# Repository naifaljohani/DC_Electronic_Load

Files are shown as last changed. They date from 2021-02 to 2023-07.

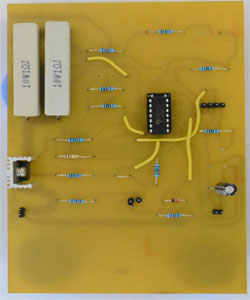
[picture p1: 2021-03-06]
Hardware/Mosfet circuit.JPG

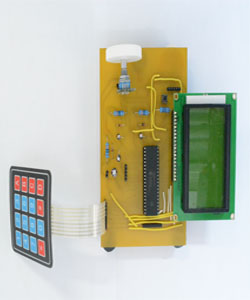
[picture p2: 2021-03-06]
Hardware/controlboard.jpg

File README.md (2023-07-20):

This is a proof of concept for a basic implementation using PIC16F1779 MCU from Microchip Technologies which has a plenty of analog features that could be very helpful to design an Electronic DC load that is affordable with acceptable features and performance.

-------------------- Project pictures----- v0--- now archive--

Mosfet circuit

controlboard

-------------------- Project pictures----- v1







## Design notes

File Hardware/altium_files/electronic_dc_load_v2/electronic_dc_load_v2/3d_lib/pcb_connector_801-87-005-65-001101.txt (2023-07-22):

"Symbol";"Value";"Unit";
"TraceParts.PartNumber";"10-20122013-093719";"";
"REFERENCE";"801-87-005-65-001101";"";
"TraceParts.PartTitle";"Press-fit socket connector 2.54 mm, single row, compliant pin for PCB thickness 1.5 to 2.5 mm - Mating pin Ø 0.76 mm";"";
"TraceParts.InstanceId";"10-20122013-0937193XV6ZG86OUMGCBDYINW9DIJ34";"";
"DESIGN";"Press-fit socket connector 2.54 mm, single row, compliant pin for PCB thickness 1.5 to 2.5 mm, 5 contacts, Tin / Flash Gold";"";
"TraceParts.PartStatus";"Published";"";
"TraceParts.PartStatusId";"";"";
"SUPPLIER";"preci-dip";"";
"TraceParts.PartVersion";"1.0.9";"";
"TRACEPARTS";"TRACEPARTS";"";
"TraceParts.PartLanguage";"en";"";
"TraceParts.ClassPath";"PRECIDIP:10-20122013-093719";"";

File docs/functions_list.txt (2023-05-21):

MCU firmware function list:
1.	Serial command scan:
a.	USART interrupt on command receive.   
2.	Serial data podcasting.
a.	USART interrupt on command transmit.
3.	Safety events reactions:
a.	Over heat event set load shut off.
b.	Voltage overload set load shut off.
c.	Current overload set load shut off.
4.	ADC functions :
a.	Initialization. 
b.	Read.
5.	DAC functions:
a.	Initialization. 
b.	Write.
6.	Mode control:
a.	Mode parameters set.
b.	Constant current PID control.
c.	Constant voltage PID control.
d.	Constant resistance PID control.
e.	Constant power PID control.
f.	Load on off.
7.	External Triggering:
a.	Triggering parameters set.
b.	External interrupt to load control.
8.	Output functions:
a.	 Square wave parameters set.

GUI functions and threads:
1.	Thread to display:
a.	Labels for current, voltage, resistance, power, mode selection.
b.	Buttons to set parameters:
i.	CC
ii.	CV
iii.	CR
iv.	CW
v.	EX TRIG
vi.	F(x)
vii.	SET
viii.	ON/OFF
ix.	Data logging.
c.	Menu to choose:
i.	Output function.
2.	Thread for ON/OFF command.
3.	Thread for parameters transmission.
4.	Thread for data logging.

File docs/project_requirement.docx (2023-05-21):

The final project is to be a USB controlled Electronic DC load, with the following features:

1. Current range of "5A -15mA".( to be verified)
2. Voltage range of "50V-1mV".( to be verified)
3. Connecting to a USB port as a serial device.
4. Controlled via an application GUI throw the serial port.
5. Powered via USB. (to be verified)
6. Has the four basic modes: CC, CV, CR, and CW.
7. Data logging in any mode.
8. External triggering.
9. Output functions, initially square wave.

Communications of data internally between functions and externally:

1. Static :
  a. Average rate
  b. Maximum rate
  c. Peak rate
2. Dynamic(FIFO):
  a. Average rate
  b. Maximum rate
  c. Peak rate

Timing:

1. Total execution time of the main function.
2. Rate of execution with a tolerance of ….+-. (to be added to the function list)
3. Response time with a tolerance of ….+- . (to be added to the function list)

Preliminary list of system modes with short description:

1. Powered down:
2. Idle:
3. Constant current:
4. Constant voltage:
5. Constant resistance:
6. Constant power:
7. External triggering:
8. Output functions:
9. Error :

Priority list: (for function execution)

1. Powered down:
2. Idle mode:
  a. High priority:
    i. …….
    ii. ………
  b. Medium priority:
    i. …….
  c. Low priority:
    i. …….
3. Constant current:
4. Constant voltage:
5. Constant resistance:
6. Constant power:
7. External triggering:
8. Output functions:
9. Error :

Mode execution based on the following triggering events table:

Original Mode | Next Mode | Triggering Event
Powered down | Error | Initial power up

Housekeeping functions (has no particular priority and execution time)

Error handling : ( a list with how it will be detected and how the system should respond to it)

1. Soft errors.
  a. Fault ……
    i. Test:
    ii. Response:
2. Recoverable errors.
  a. Fault ……
    i. Test:
    ii. Response:
3. Unrecoverable errors.
  a. Fault ……
    i. Test:
    ii. Response:
4. Hard errors:
  a. Watch dog timer
  b. Brownout reset
  c. Program data corruption
  d. Fault ……
    i. Test:
    ii. Response:

Task list: (list of tasks contains a set of functions, combining tasks is desirable if compatible, if not, a separation of incompatible tasks in timing or peripherals or has any conflict in any aspect, is easier to manage and less overhead)

1. Task1:
  a. Function1.
  b. Function2.
  c. …….

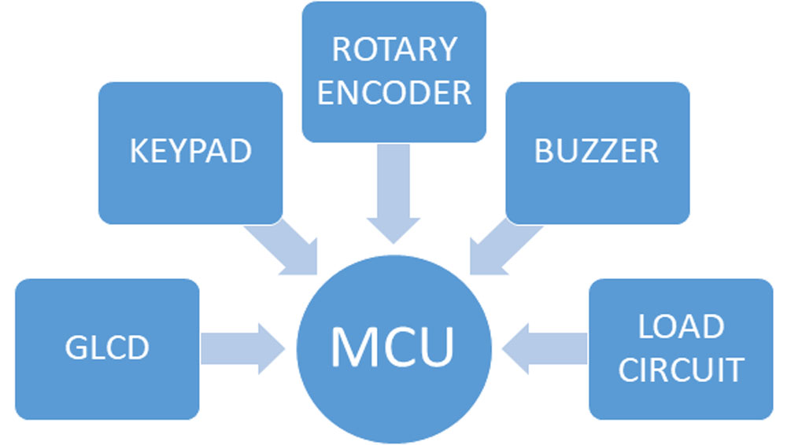
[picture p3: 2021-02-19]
Hardware/BLOCK_DIAGRAM.jpg

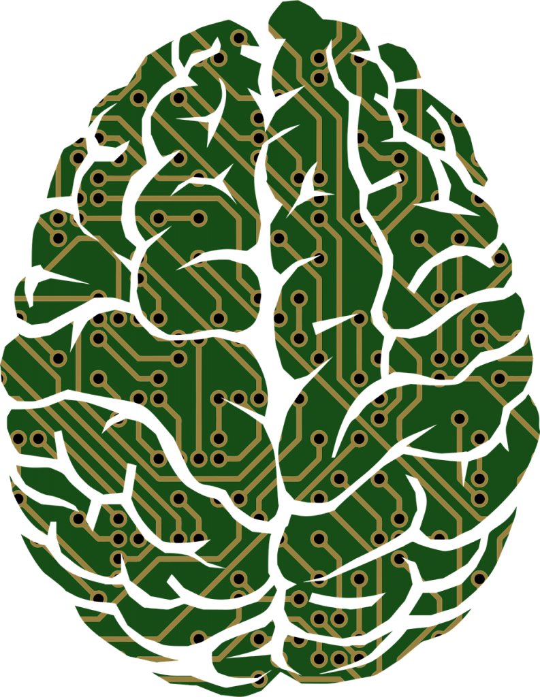
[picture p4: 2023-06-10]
Firmware/latex/nmn,.jpg

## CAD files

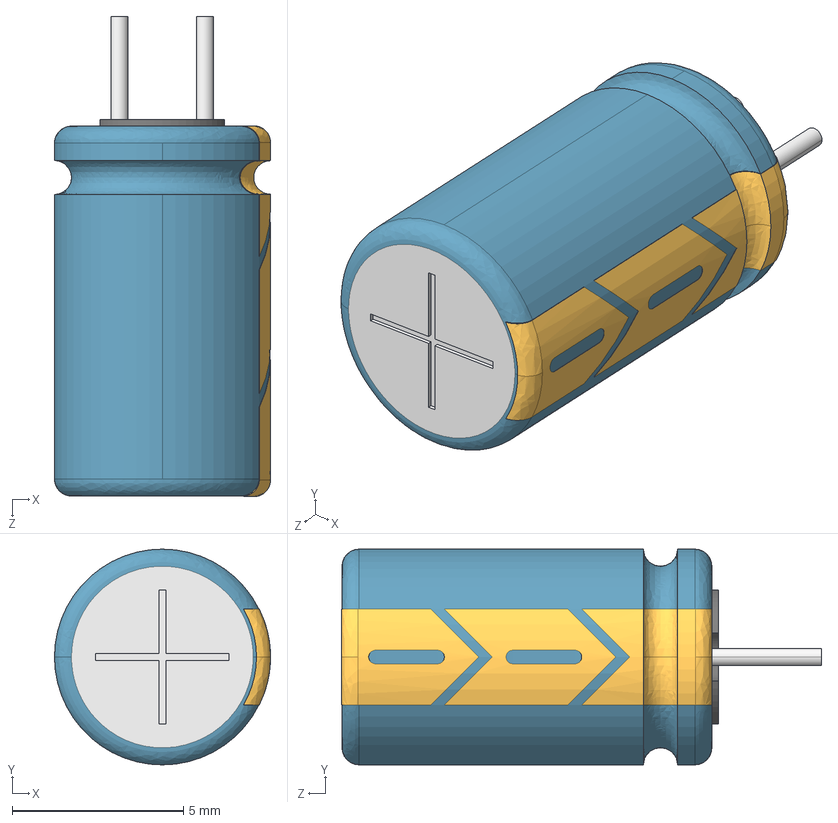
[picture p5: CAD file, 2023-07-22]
Hardware/altium_files/electronic_dc_load_v2/electronic_dc_load_v2/3d_lib/User Library-CAPAER_D063_L110_P025_W005X030.STEP
6.31 x 6.30 x 14.0 mm

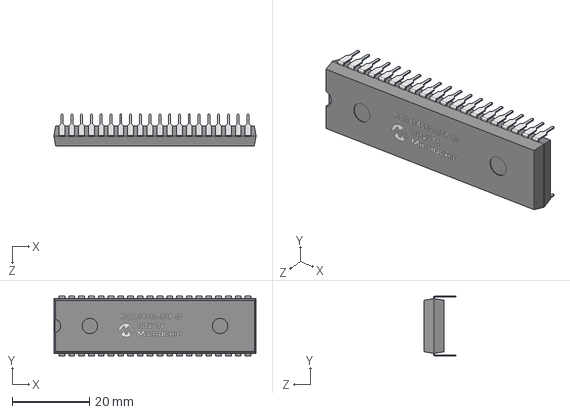
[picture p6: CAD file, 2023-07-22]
Hardware/altium_files/electronic_dc_load_v2/electronic_dc_load_v2/3d_lib/User Library-PIC18F4550-DIP40-600.step
52.5 x 15.5 x 8.28 mm

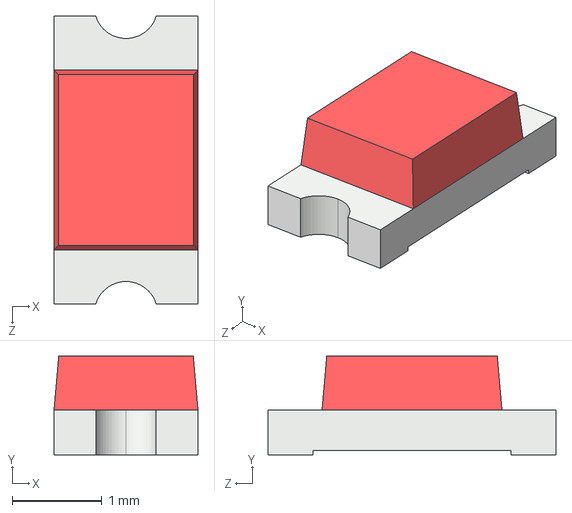
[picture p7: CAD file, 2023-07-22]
Hardware/altium_files/electronic_dc_load_v2/electronic_dc_load_v2/3d_lib/User Library-LED 1206 RED.step
1.60 x 1.10 x 3.20 mm

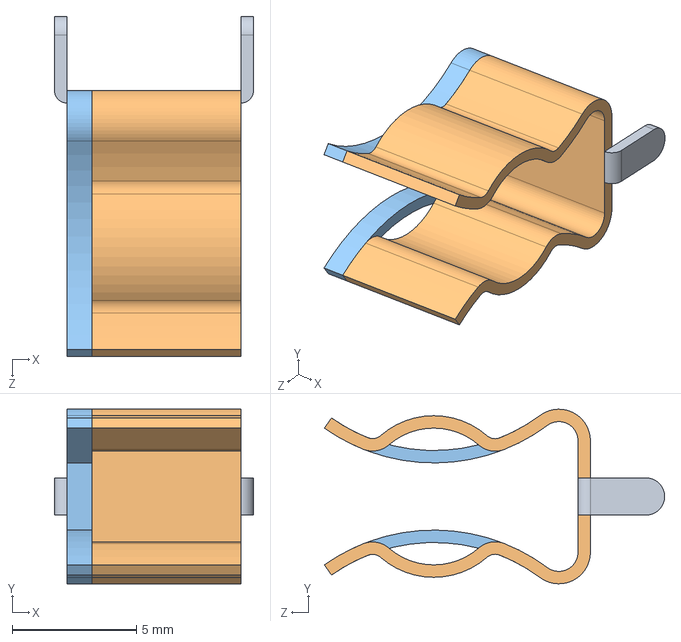
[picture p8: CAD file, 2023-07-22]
Hardware/altium_files/electronic_dc_load_v2/electronic_dc_load_v2/3d_lib/User Library-FH-103 fuse holder 6_4mm.STEP
8.00 x 7.02 x 13.7 mm

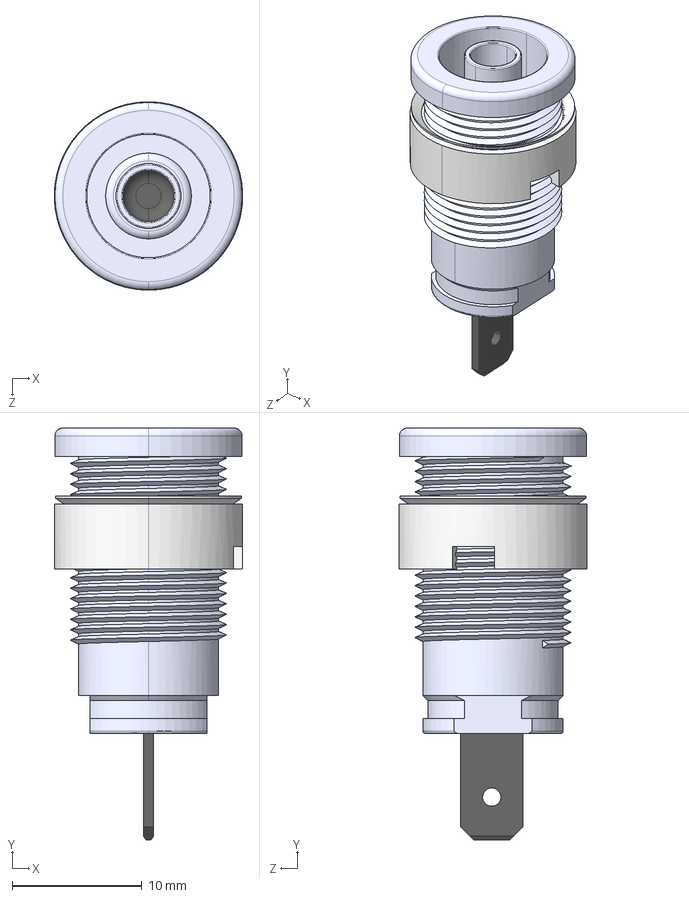
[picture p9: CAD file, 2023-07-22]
Hardware/altium_files/electronic_dc_load_v2/electronic_dc_load_v2/3d_lib/User Library-Banana jack-1.STEP
14.5 x 31.7 x 14.5 mm
Stor banan
Stor banan koppar
Stor banan mutter
Stor banan bricka

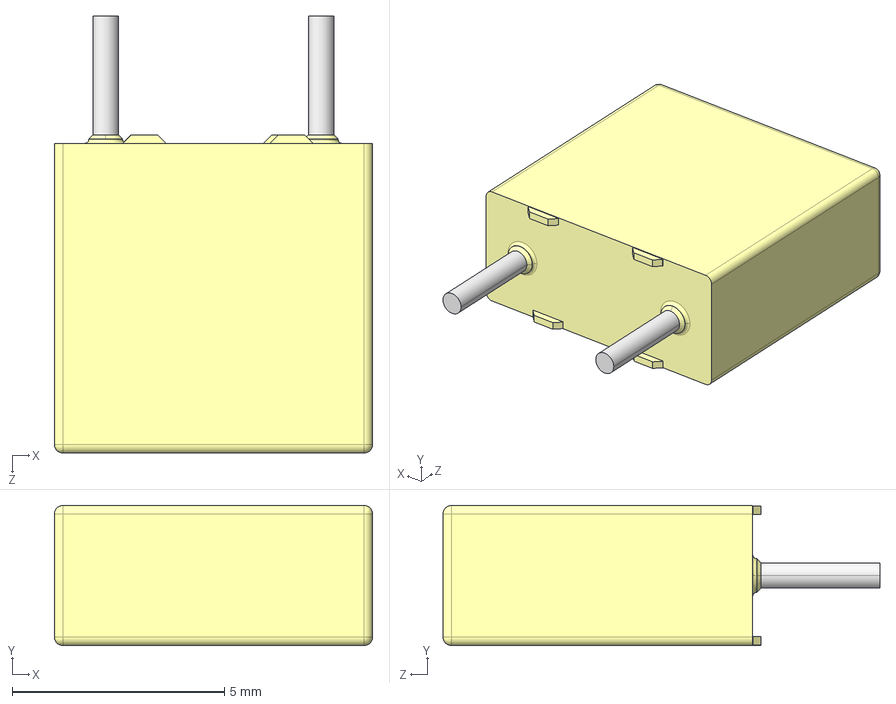
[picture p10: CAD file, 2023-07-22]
Hardware/altium_files/electronic_dc_load_v2/electronic_dc_load_v2/3d_lib/User Library-CapFilmBox_508.STEP
7.50 x 3.30 x 10.3 mm
CapFilmBox_508
Lead1
lead2

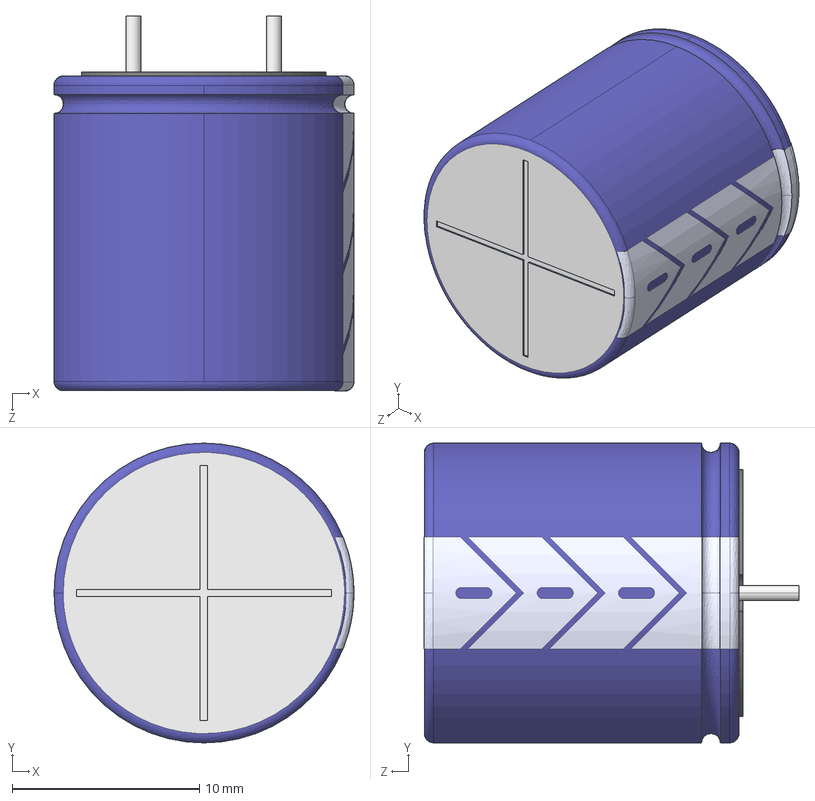
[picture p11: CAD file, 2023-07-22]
Hardware/altium_files/electronic_dc_load_v2/electronic_dc_load_v2/3d_lib/User Library-CAPAER_D160_L170_P075_W008X030.STEP
16.0 x 16.0 x 20.0 mm

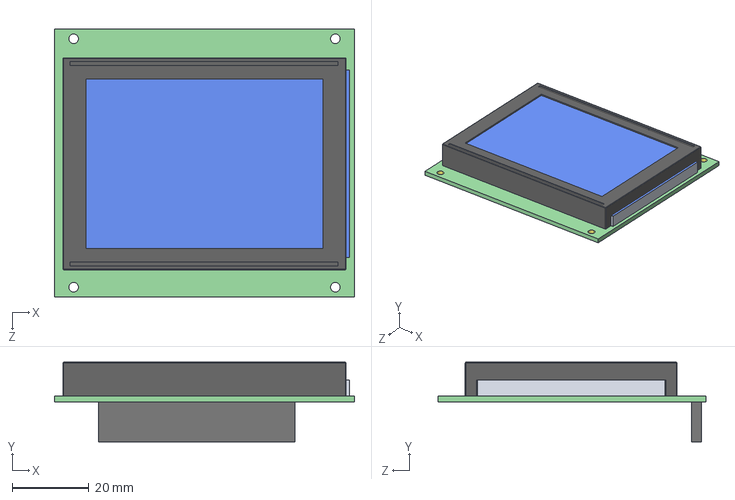
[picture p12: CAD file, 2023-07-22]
Hardware/altium_files/electronic_dc_load_v2/electronic_dc_load_v2/3d_lib/User Library-GLCD 128x64.step
78.4 x 20.8 x 70.0 mm

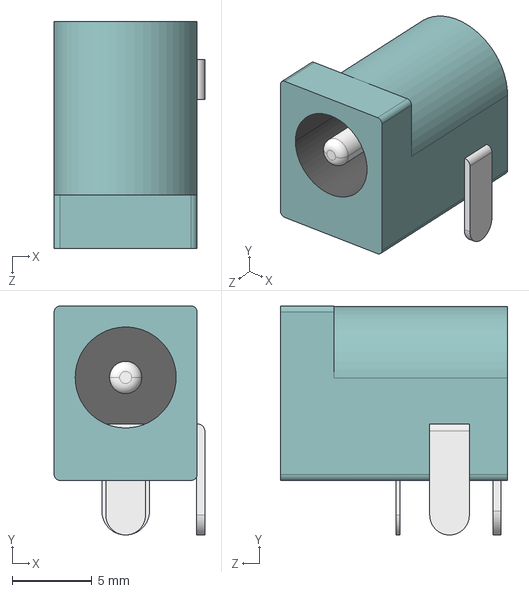
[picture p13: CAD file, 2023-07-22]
Hardware/altium_files/electronic_dc_load_v2/electronic_dc_load_v2/3d_lib/User Library-RAPC722 Audio Jack.step
9.47 x 14.4 x 14.2 mm

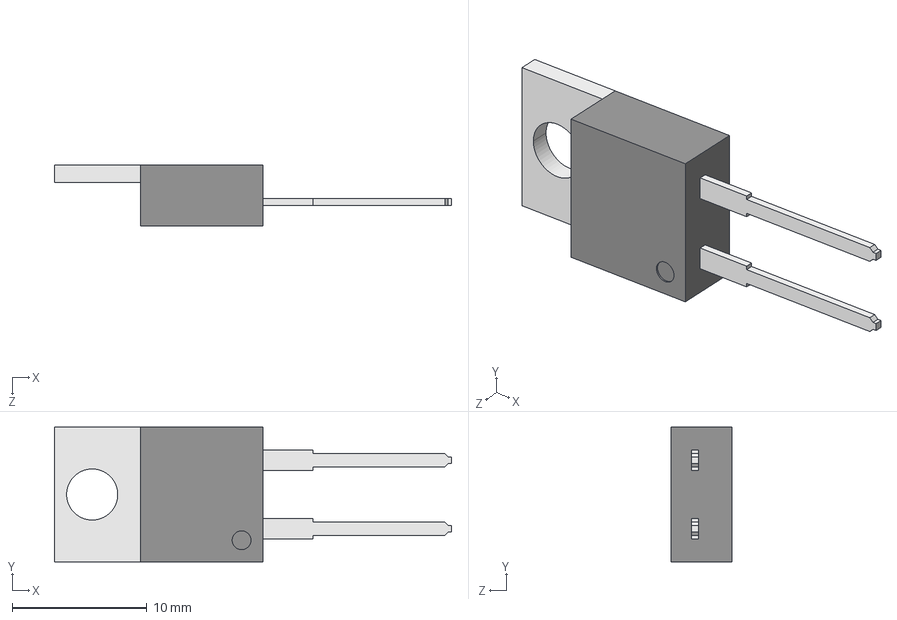
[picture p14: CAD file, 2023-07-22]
Hardware/altium_files/electronic_dc_load_v2/electronic_dc_load_v2/3d_lib/User Library-TO220-2_V-L.STEP
29.5 x 10.0 x 4.50 mm
TO220_3_V_L004

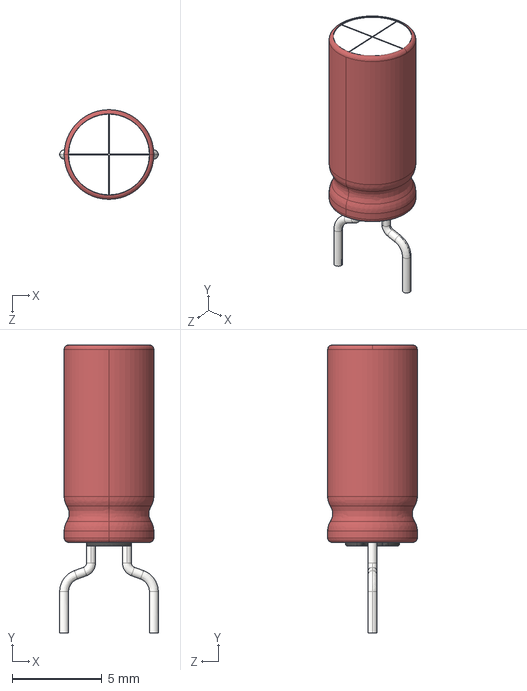
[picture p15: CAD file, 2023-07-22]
Hardware/altium_files/electronic_dc_load_v2/electronic_dc_load_v2/3d_lib/User Library-CAP_5X11_P5.step
5.50 x 16.0 x 5.00 mm

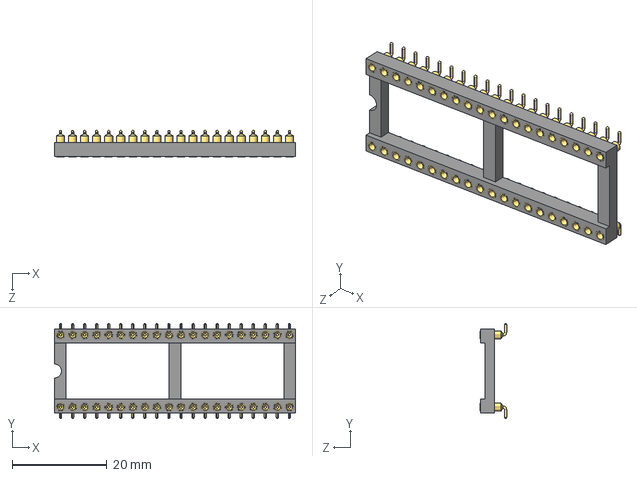
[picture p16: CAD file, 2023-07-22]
Hardware/altium_files/electronic_dc_load_v2/electronic_dc_load_v2/3d_lib/User Library-40pin 0_6inch 2_54mm IC DIP-SMD Socket Round Hole.step
50.8 x 20.0 x 5.59 mm

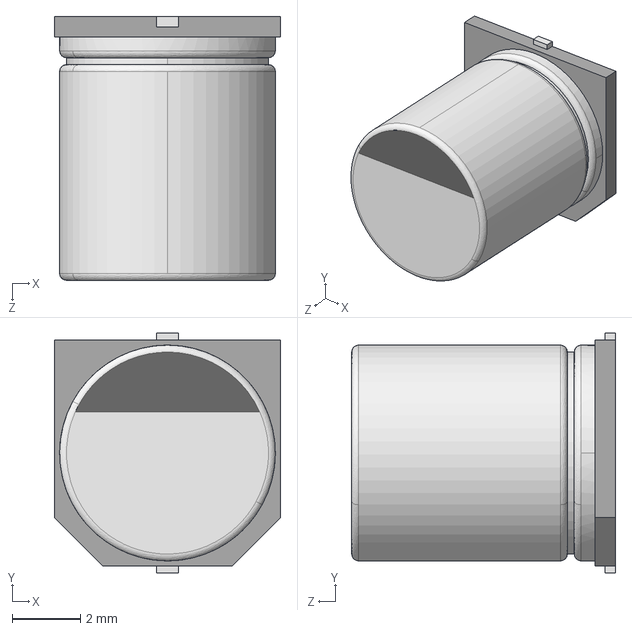
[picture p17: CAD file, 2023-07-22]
Hardware/altium_files/electronic_dc_load_v2/electronic_dc_load_v2/3d_lib/User Library-capacitor size D8.STEP
6.60 x 7.00 x 7.71 mm

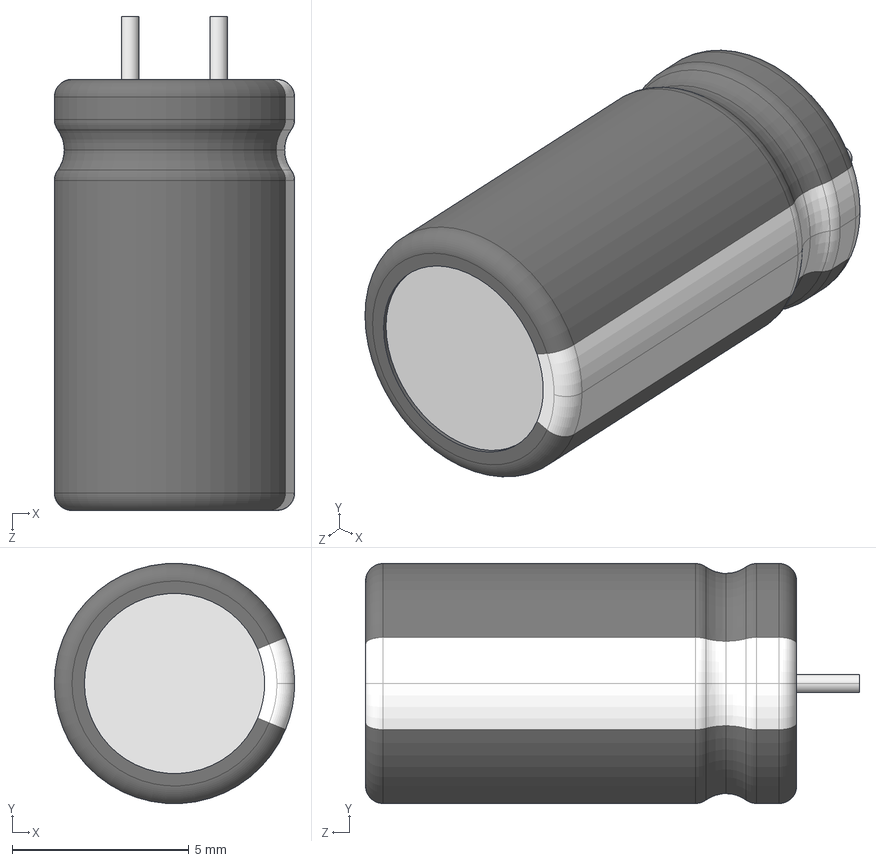
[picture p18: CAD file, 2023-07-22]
Hardware/altium_files/electronic_dc_load_v2/electronic_dc_load_v2/3d_lib/User Library-Aluminum Electrolytic Capacitors.STEP
6.80 x 6.79 x 14.0 mm

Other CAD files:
Firmware/dist/default/production/Firmware.production.obj
Firmware/source/source.X/dist/default/production/source.X.production.obj
Firmware/dist/default/production/ELECTRONIC_LOAD_2020.X.production.obj
Hardware/altium_files/electronic_dc_load_v2/electronic_dc_load_v2/3d_lib/TCH-506-8700900.step
Firmware/archive/dist/default/production/ELECTRONIC_LOAD_2020.X.production.obj
Firmware/archive/dist/default/production/Firmware.production.obj
Hardware/altium_files/electronic_dc_load_v2/electronic_dc_load_v2/3d_lib/11964.stp
Hardware/altium_files/electronic_dc_load_v2/electronic_dc_load_v2/3d_lib/350-80-102-00-006101.stp
Hardware/altium_files/electronic_dc_load_v2/electronic_dc_load_v2/3d_lib/70410275.stp
Hardware/altium_files/electronic_dc_load_v2/electronic_dc_load_v2/3d_lib/71071832.stp
Hardware/altium_files/electronic_dc_load_v2/electronic_dc_load_v2/3d_lib/ALSRobot-TO-220-3.STEP
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

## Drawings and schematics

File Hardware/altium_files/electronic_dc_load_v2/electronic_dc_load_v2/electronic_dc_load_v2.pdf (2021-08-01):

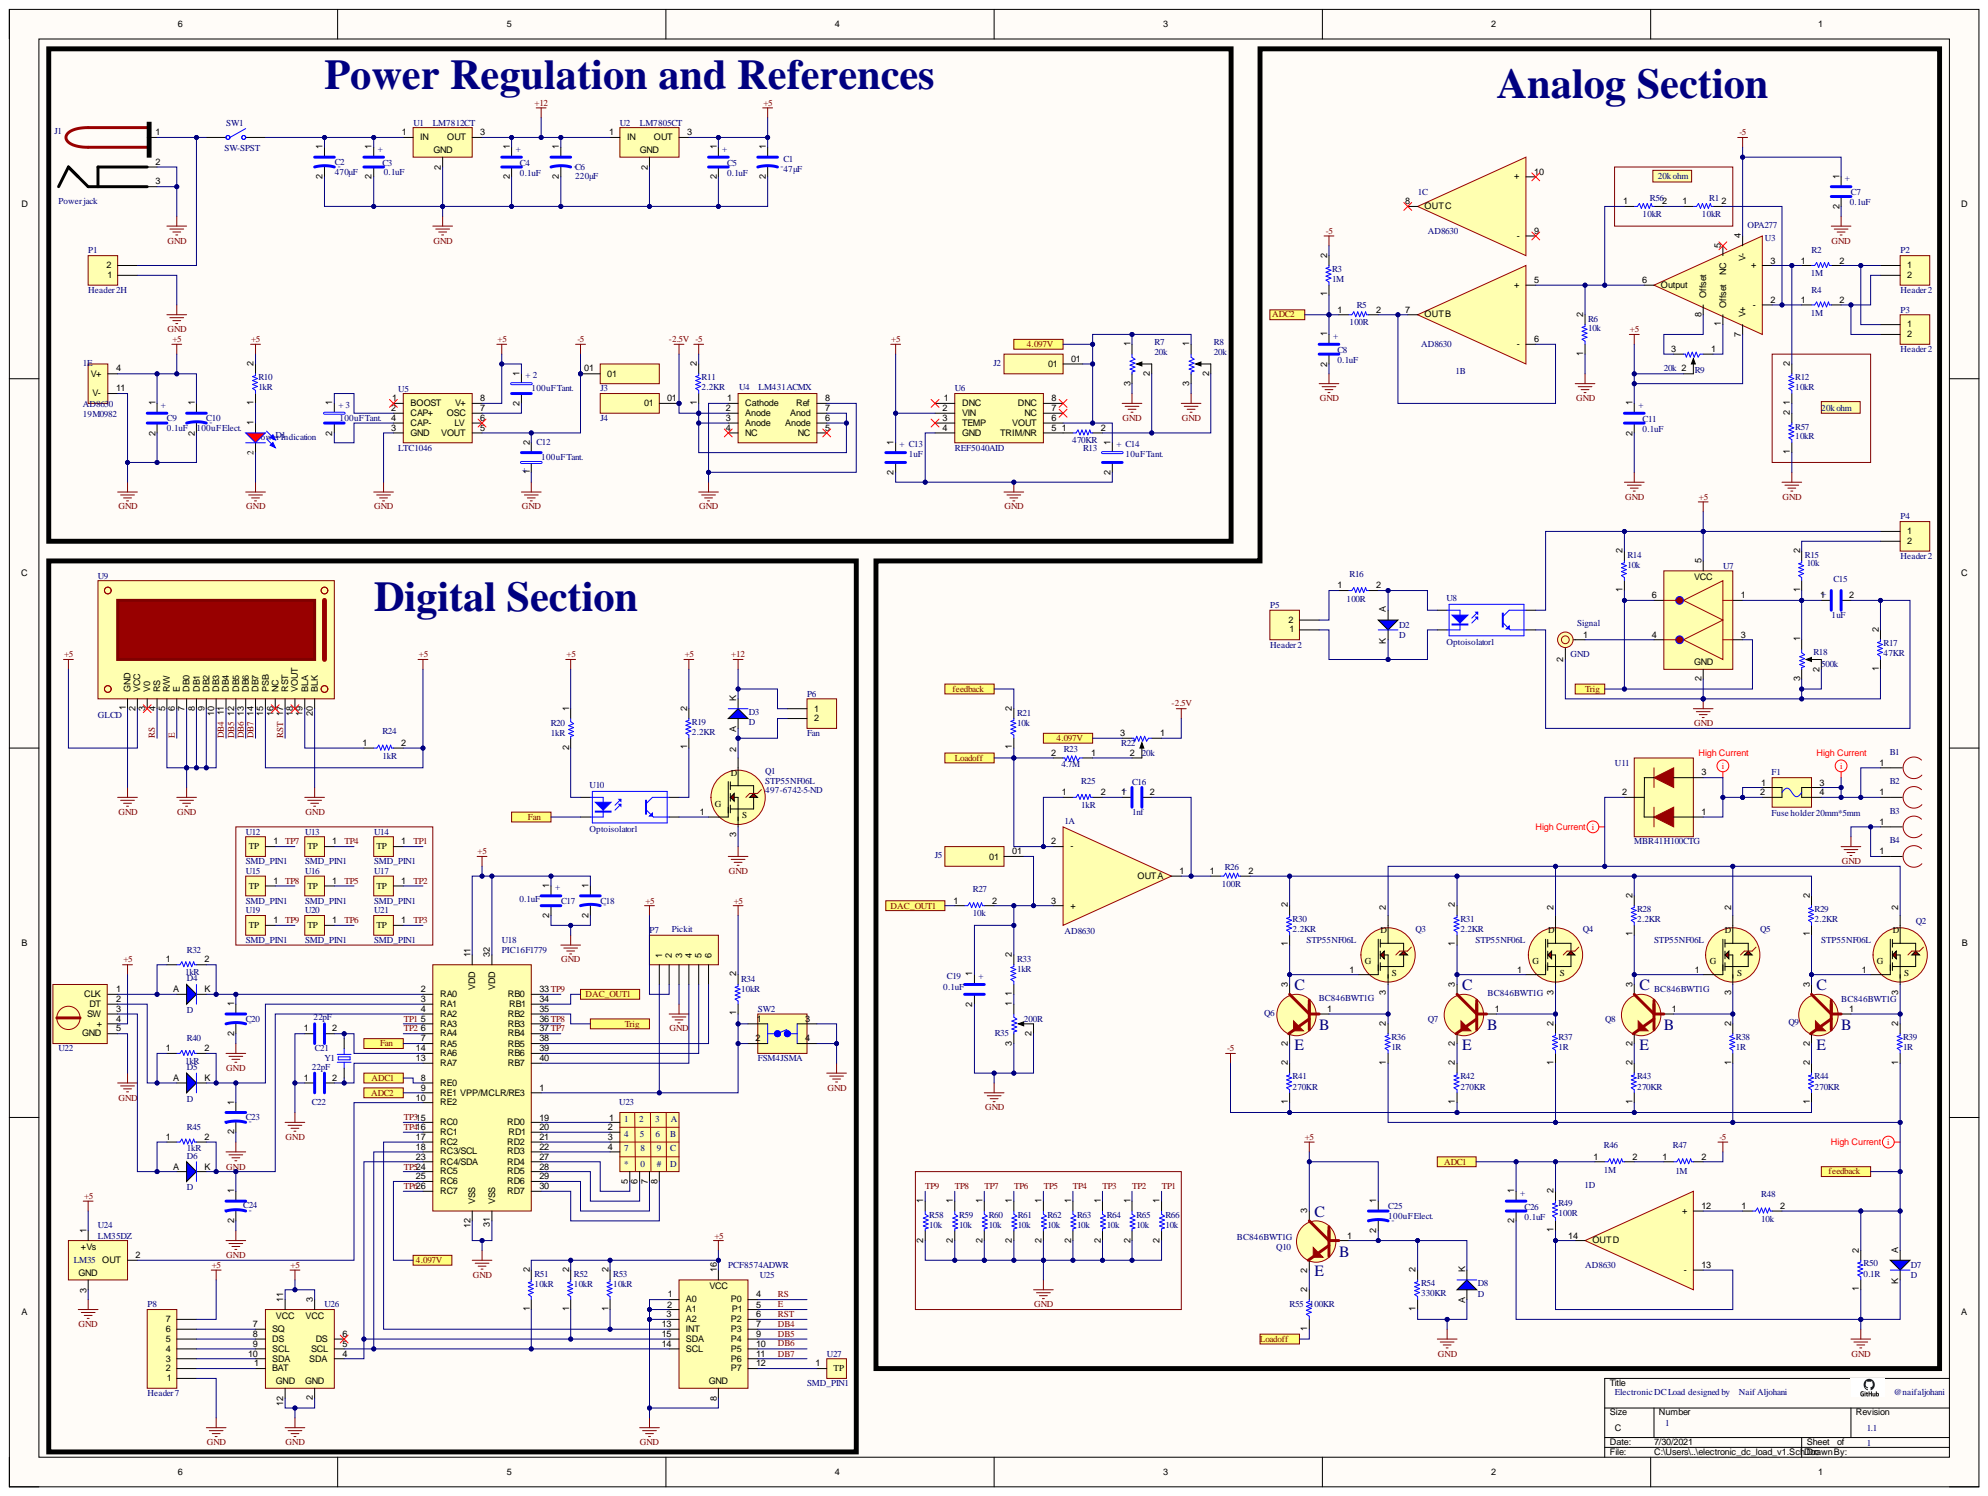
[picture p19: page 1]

Power Regulation and References

GND

RC3/SCL 18 RD3 | 22 4 | 7 | 8 | 9 | C

3 SDA 4 SCL 5 DS 6 SQ 7
VCC

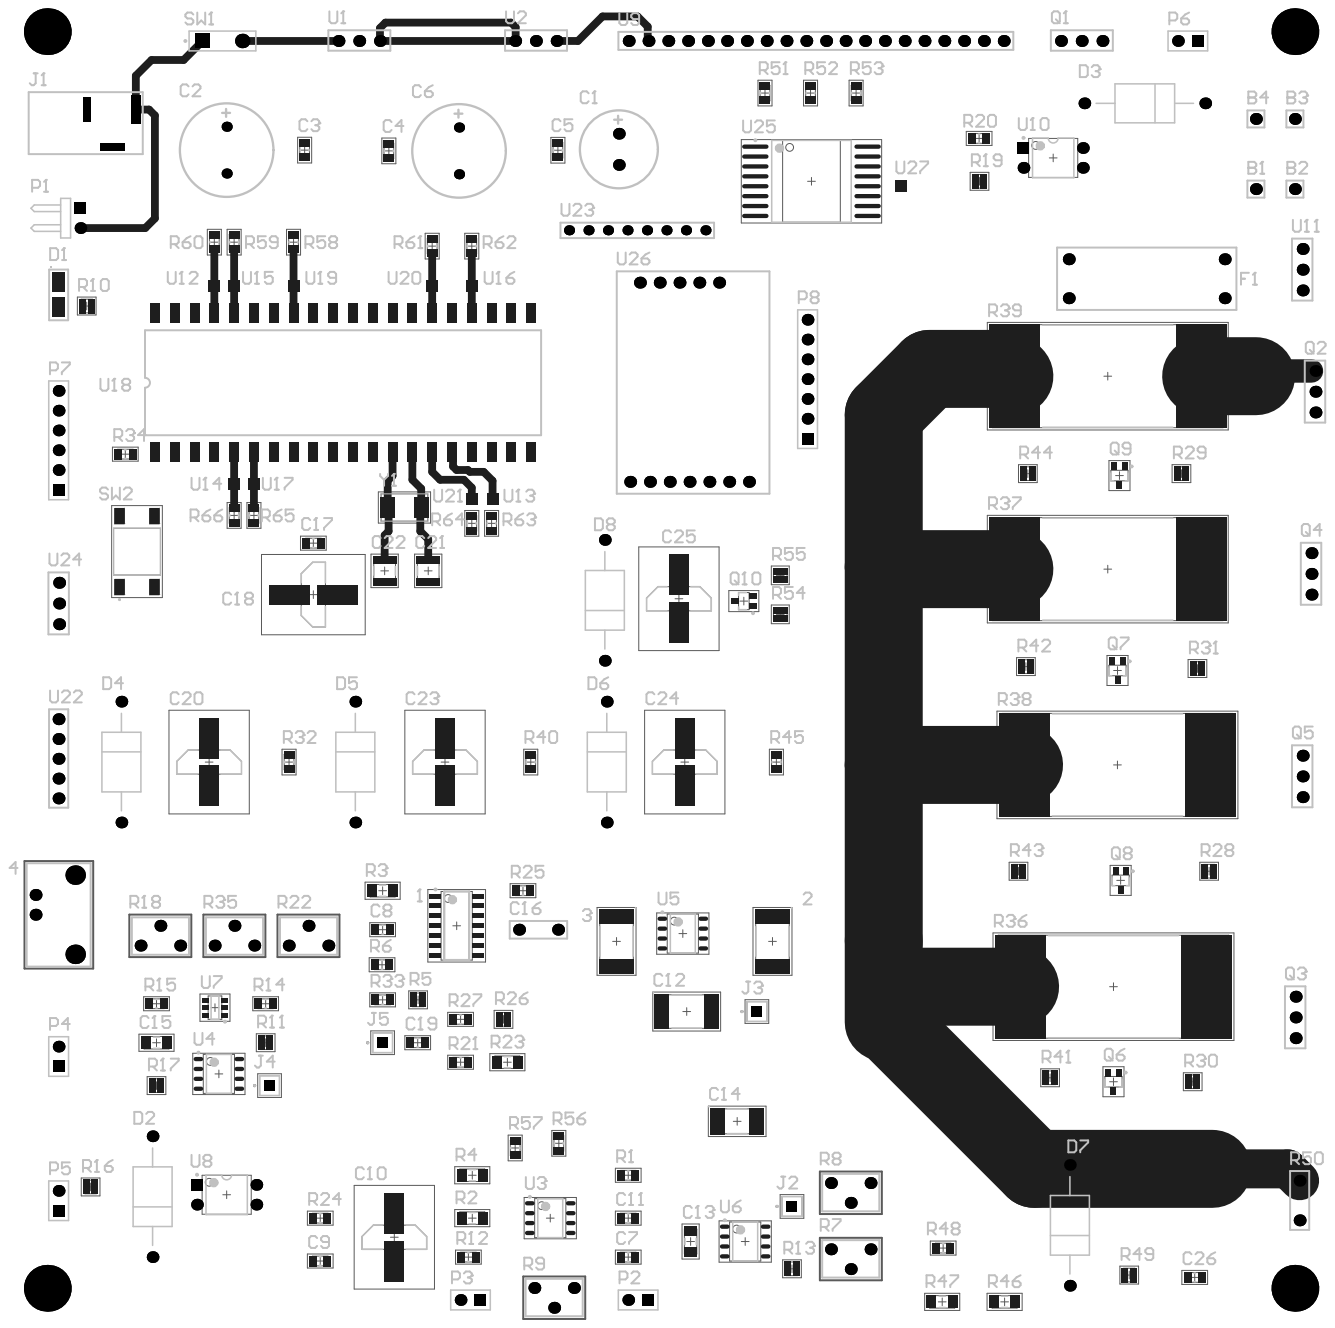
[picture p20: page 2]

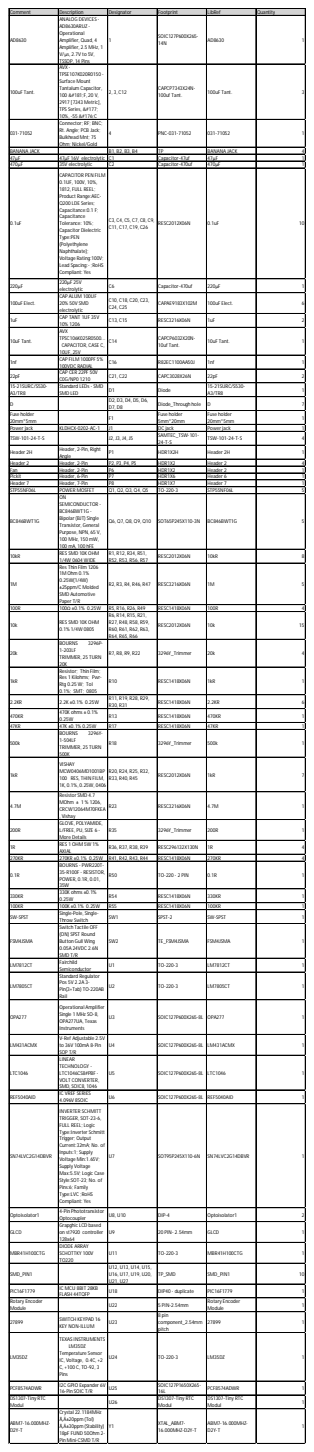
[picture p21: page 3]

100uF Tant. | AVX -TPSE107K020R0150 -Surface Mount Tantalum Capacitor, 100 &#181;F, 20 V, 2917 [7343 Metric], TPS Series, &#177; 10%, -55 &#176;C | 2, 3, C12 | CAPCP7343X24N-100uf Tant. | 100uF Tant. | | 3

031-71052 | Connector; RF; BNC; Rt. Angle; PCB Jack; Bulkhead Mnt; 75 Ohm; Nickel/Gold | 4 | PNC-031-71052 | 031-71052 | | 1

BANANA JACK 47μF | 47μF 16V electrolytic | B1, B2, B3, B4 C1 | TP Capacitor-47uf | BANANA JACK 47μF | | 4 1

470μF | 35V electrolytic | C2 | Capacitor-470uf | 470μF | | 1

0.1uF | CAPACITOR PEN FILM 0.1UF, 100V, 10%, 1812, FULL REEL; Product Range:AEC-Q200 LDE Series; Capacitance:0.1 F; Capacitance Tolerance: 10%; Capacitor Dielectric Type:PEN (Polyethylene Naphthalate); Voltage Rating:100V; Lead Spacing:- ;RoHS Compliant: Yes | C3, C4, C5, C7, C8, C9, C11, C17, C19, C26 | RESC2012X06N | 0.1uF | 10

220μF | 220μF 25V electrolytic | C6 | Capacitor-470uf | 220μF | | 1

100uF Elect. | CAP ALUM 100UF 20% 50V SMD electrolytic | C10, C18, C20, C23, C24, C25 | CAPAE9183X102M | 100uF Elect. | | 6

1uF | CAP TANT 1UF 35V 10% 1206 | C13, C15 | RESC3216X06N | 1uF | | 2

10uF Tant. | AVX TPSC106K025R0500... CAPACITOR, CASE C, 10UF, 25V | C14 | CAPCP6032X20N-10uf Tant. | 10uF Tant. | | 1

1nf | CAP FILM 1000PF 5% 100VDC RADIAL | C16 | R82EC1100AA50J | 1nf | | 1

22pF | CAP CER 22PF 50V C0G/NP0 1210 | C21, C22 | CAPC3028X26N | 22pF | | 2

15-21SURC/S530-A3/TR8 | Standard LEDs - SMD SMD LED | D1 | Diode | 15-21SURC/S530-A3/TR8 | | 1

D | | D2, D3, D4, D5, D6, D7, D8 | Diode_Through hole | D | | 7

Fuse holder 20mm*5mm | | F1 | Fuse holder 5mm*20mm | Fuse holder 20mm*5mm | | 1

Power jack | KLDHCX-0202-AC-1 | J1 | DC jack | Power jack | | 1
TSW-101-24-T-S | | J2, J3, J4, J5 | SAMTEC_TSW-101-24-T-S | TSW-101-24-T-S | | 4

Header 2H | Header, 2-Pin, Right Angle | P1 | HDR1X2H | Header 2H | | 1

Header 2 | Header, 2-Pin | P2, P3, P4, P5 | HDR1X2 | Header 2 | | 4
Fan | Header, 2-Pin | P6 | HDR1X2 | Header 2 | | 1
Pickit Header 7 | Header, 6-Pin Header, 7-Pin | P7 P8 | HDR1X6 HDR1X7 | Header 6 Header 7 | | 1 1

STP55NF06L | POWER MOSFET | Q1, Q2, Q3, Q4, Q5 | TO-220-3 | STP55NF06L | | 5
BC846BWT1G | ON SEMICONDUCTOR -BC846BWT1G -Bipolar (BJT) Single Transistor, General Purpose, NPN, 65 V, 100 MHz, 150 mW, 100 mA, 100 hFE | Q6, Q7, Q8, Q9, Q10 | SOT65P245X110-3N | BC846BWT1G | | 5

10kR | RES SMD 10K OHM 1/4W 0604 WIDE | R1, R12, R34, R51, R52, R53, R56, R57 | RESC2012X06N | 10kR | | 8

1M | Res Thin Film 1206 1M Ohm 0.1% 0.25W(1/4W) ±25ppm/C Molded SMD Automotive Paper T/R | R2, R3, R4, R46, R47 | RESC3216X06N | 1M | | 5

100R 10k | 100Ω ±0.1% 0.25W RES SMD 10K OHM 0.1% 1/4W 0805 | R5, R16, R26, R49 R6, R14, R15, R21, R27, R48, R58, R59, R60, R61, R62, R63, R64, R65, R66 | RESC1418X06N RESC2012X06N | 100R 10k | 15 | 4

20k | BOURNS 3296P-1-203LF TRIMMER, 25 TURN 20K | R7, R8, R9, R22 | 3296Y_Trimmer | 20k | 4

1kR | Resistor; Thin Film; Res 1 Kilohms; Pwr-Rtg 0.25 W; Tol 0.1%; SMT; 0805 | R10 | RESC1418X06N | 1kR | 1

2.2KR | 2.2K ±0.1% 0.25W | R11, R19, R28, R29, R30, R31 | RESC1418X06N | 2.2KR | 6

470KR | 470K ohms ± 0.1% 0.25W | R13 | RESC1418X06N | 470KR | 1

47KR | 47K ±0.1% 0.25W | R17 | RESC1418X06N | 47KR | 1
500k | BOURNS 1-504LF 3296Y-TRIMMER, 25 TURN 500K | R18 | 3296Y_Trimmer | 500k | 1

1kR | VISHAY MCW0406MD1001BP 100 RES, THIN FILM, 1K, 0.1%, 0.25W, 0406 | R20, R24, R25, R32, R33, R40, R45 | RESC2012X06N | 1kR | 7

4.7M | Resistor SMD 4.7 MOhm ± 1 % 1206, CRCW12064M70FKEA , Vishay | R23 | RESC3216X06N | 4.7M | 1

200R | GLOVE, POLYAMIDE, L/FREE, PU, SIZE 6 -More Details | R35 | 3296Y_Trimmer | 200R | 1

1R | RES 1 OHM 5W 1% AXIAL | R36, R37, R38, R39 | RESC296132X130N | 1R | 4

270KR | 270KR ±0.1% 0.25W | R41, R42, R43, R44 | RESC1418X06N | 270KR | 4
0.1R | BOURNS - PWR220T-35-R100F - RESISTOR, POWER, 0.1R, 0.01, 35W | R50 | TO-220 - 2 PIN | 0.1R | 1

330KR | 330K ohms ±0.1% 0.25W | R54 | RESC1418X06N | 330KR | 1

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

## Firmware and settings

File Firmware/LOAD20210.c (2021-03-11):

#include "ADC.h"
#include "GLCD.h"
#include "LDC_ROT.h"
#include <stdio.h>
#include <stdlib.h>
#include <xc.h>
#include "string.h"
#include <stdint.h>
#include <stdbool.h>



#define _XTAL_FREQ             16000000
#define Encoder_DT             PORTAbits.RA0 
#define Encoder_CLOCK          PORTAbits.RA1
#define Button_Press           PORTAbits.RA3
#define UP                     PORTAbits.RA4
#define DOWN                   PORTAbits.RA5




#define X_1    LATDbits.LATD0
#define X_2    LATDbits.LATD1
#define X_3    LATDbits.LATD2
#define X_4    LATDbits.LATD3
#define Y_1    PORTDbits.RD4
#define Y_2    PORTDbits.RD5
#define Y_3    PORTDbits.RD6
#define Y_4    PORTDbits.RD7

///#define Keypad_PORT               LATD
#define Keypad_PORT_Direction     TRISD 


char naif[17]={' ',' ',' ',' ',' ',' ',' ',' ',' ',' ',' ',' ',' ',' ',' ',' ','\0'};
char UPDOWN[17]={' ',' ',' ',' ',' ',' ',' ',' ',' ',' ',' ',' ',' ',' ',' ',' ','\0'};
unsigned char hello[25]="naif hamdi aljohani   ";
char Key = 'n';

  uint16_t dac_out =0;

  int16_t  count = 520;
  float   current = 0;
  
 unsigned char print_line = 3;
 
 int currentStateCLK;
 int previousStateCLK;
 
 
void InitKeypad(void);
char switch_press_scan(void);

char keypad_scanner(void)  
{           
            X_1 = 0; X_2 = 1; X_3 = 1; X_4 = 1;    
            if (Y_1 == 0) { __delay_ms(100); while (Y_1==0); return '1'; }
            if (Y_2 == 0) { __delay_ms(100); while (Y_2==0); return '2'; }
            if (Y_3 == 0) { __delay_ms(100); while (Y_3==0); return '3'; }
            if (Y_4 == 0) { __delay_ms(100); while (Y_4==0); return 'A'; }
            
            X_1 = 1; X_2 = 0; X_3 = 1; X_4 = 1;    
            if (Y_1 == 0) { __delay_ms(100); while (Y_1==0); return '4'; }
            if (Y_2 == 0) { __delay_ms(100); while (Y_2==0); return '5'; }
            if (Y_3 == 0) { __delay_ms(100); while (Y_3==0); return '6'; }
            if (Y_4 == 0) { __delay_ms(100); while (Y_4==0); return 'B'; }
            
            X_1 = 1; X_2 = 1; X_3 = 0; X_4 = 1;    
            if (Y_1 == 0) { __delay_ms(100); while (Y_1==0); return '7'; }
            if (Y_2 == 0) { __delay_ms(100); while (Y_2==0); return '8'; }
            if (Y_3 == 0) { __delay_ms(100); while (Y_3==0); return '9'; }
            if (Y_4 == 0) { __delay_ms(100); while (Y_4==0); return 'C'; }
           
            X_1 = 1; X_2 = 1; X_3 = 1; X_4 = 0;    
            if (Y_1 == 0) { __delay_ms(100); while (Y_1==0); return '*'; }
            if (Y_2 == 0) { __delay_ms(100); while (Y_2==0); return '0'; }
            if (Y_3 == 0) { __delay_ms(100); while (Y_3==0); return '#'; }
            if (Y_4 == 0) { __delay_ms(100); while (Y_4==0); return 'D'; }
            
    return ;                   
} 
void InitKeypad(void)
{
            //Keypad_PORT                = 0x00;        // Set Keypad port pin values zero       
            OPTION_REGbits.nWPUEN =0;
            Keypad_PORT_Direction = 0b11110000;      // Last 4 pins input, First 4 pins output 
            WPUD = 0b11110000;
            ANSELD=0;
}

void OP_AMP_init()
{
    // OPA3ORPOL not inverted; OPA3EN enabled; OPA3UG OPA_Output; OPA3ORM disabled; 
    OPA3CON = 0x90;
    // ORS CCP1_out; 
    OPA3ORS = 0x00;
    // NCH OPA3IN0-; 
    OPA3NCHS = 0x00;
    // PCH DAC5_out; 
    OPA3PCHS = 0x02;
}
 
 
void interrupt_init()
{
  GIE   = 1  ; 
  IOCIE = 1 ;
  IOCAP3=1;
}
void interrupt isr()
{
   
   if (IOCAF3 == 1) // button pressed 
   {
     IOCAF3 =0;    //  clear flag   
    
     count=0;
   
     
   }
     
}


void main(void)
{
  ///  IOCIF  , IOCAFx            ///Interrupt-on-Change Interrupt Flag bit  
  OSCILLATOR_Initialize();  
  //interrupt_init();
  DAC_CONFIG();                  // DAC ON PIN RA2 !
  OP_AMP_init();
  
  TRISC = 0xBF;
  ANSELC = 0xFC;
  WPUC = 0x00;
  ODCONC = 0x00;
  SLRCONC = 0xFF;
  INLVLC = 0xFF;
   
   
  TRISA=0b00001011;
  ANSELA=0;
  INLVLA=0;
  
  ADC_Initialize();
  
  
 
  TRISB=0;
  ANSELB=0; 
  ODCONB=0;
  SLRCONB=0;
 /// __delay_ms(500);
 
     InitKeypad();
  ////////////////////////// greeting maseage ///// 
    LCD_Init( );
    LCD_EnableGraphics();
    LCD_ClearGraphics();
    LCD_FillScreenGraphics(des);
    __delay_ms(1000);
    LCD_ClearGraphics();
    LCD_DisableGraphics();  
    
    
    previousStateCLK = Encoder_CLOCK;
 
   
   
  while(1)
  {
   current=  (ADC_GetConversion(channel_AN5)* 0.004882812);  
   
   
  ///  current= ( ADC_GetConversion(channel_AN5)*5)-230; 
    naif[3]=' ';
    
    // sprintf(naif, "%.5f", current);
   
    sprintf(naif,"%.2f", (current-0.11));   // convert float to string to print on GLCD "eating 20% of code space"
    
    LCD_TextDisplayString( 3, "Current   in mA:");
    LCD_TextDisplayString( 4, naif);   
    
      
 // encoder input ///     
    if(Button_Press==0)
    {
     count =520;
    
     
    }
      
      if (Encoder_CLOCK == 0) // button pressed 
   {
    __delay_ms(10);
     currentStateCLK = Encoder_CLOCK;
    
  
     // If the inputDT state is different than the inputCLK state then 
     // the encoder is rotating counterclockwise
     if (Encoder_DT != currentStateCLK) { 
       count  --;
       if (count <520)
     {
         count  =520;
     }
       
       
     } else {
       // Encoder is rotating clockwise
       count  ++;
      
        
       
     }
     previousStateCLK = currentStateCLK;   // Update previousStateCLK with the current state
   
   }
    
    
    naif[3]=' ';
    sprintf(naif,"%.2f", (count*0.004882812) );
    LCD_TextDisplayString( 1, "DAC out       V:");
    LCD_TextDisplayString( 2, naif); 
    
           
           
   UPDOWN[1]=switch_press_scan();
  
     
      //////////////////////////////
    
     DAC5_Load10bitInputData(count*64);
      
    //  DAC1_Load10bitInputData ((naif[1]-48)*5120);
      
   
     if ( UPDOWN[1] == 'A')
     {
        count++; 
        UPDOWN[1]=' ';
     }
      if (UPDOWN[1] == 'B')
     {
        count--; 
        UPDOWN[1]=' ';
     }
   
    //  LCD_TextDisplayString(print_line, naif);
      
      
      
      }
        
        
  
   }   
    

 

 
 

 char switch_press_scan(void)                       // Get key from user
{
            char key = 'n';              // Assume no key pressed
            while(key=='n')              // Wait untill a key is pressed
            key = keypad_scanner();   // Scan the keys again and again
            return key;                  //when key pressed then return its value
}
  

 

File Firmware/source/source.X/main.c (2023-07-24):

/**
  Generated Main Source File

  Company:
    Microchip Technology Inc.

  File Name:
    main.c

  Summary:
    This is the main file generated using PIC10 / PIC12 / PIC16 / PIC18 MCUs

  Description:
    This header file provides implementations for driver APIs for all modules selected in the GUI.
    Generation Information :
        Product Revision  :  PIC10 / PIC12 / PIC16 / PIC18 MCUs - 1.81.8
        Device            :  PIC16F1779
        Driver Version    :  2.00
*/

/*
    (c) 2018 Microchip Technology Inc. and its subsidiaries. 
    
    Subject to your compliance with these terms, you may use Microchip software and any 
    derivatives exclusively with Microchip products. It is your responsibility to comply with third party 
    license terms applicable to your use of third party software (including open source software) that 
    may accompany Microchip software.
    
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
    IN NO EVENT WILL MICROCHIP BE LIABLE FOR ANY INDIRECT, SPECIAL, PUNITIVE, 
    INCIDENTAL OR CONSEQUENTIAL LOSS, DAMAGE, COST OR EXPENSE OF ANY KIND 
    WHATSOEVER RELATED TO THE SOFTWARE, HOWEVER CAUSED, EVEN IF MICROCHIP 
    HAS BEEN ADVISED OF THE POSSIBILITY OR THE DAMAGES ARE FORESEEABLE. TO 
    THE FULLEST EXTENT ALLOWED BY LAW, MICROCHIP'S TOTAL LIABILITY ON ALL 
    CLAIMS IN ANY WAY RELATED TO THIS SOFTWARE WILL NOT EXCEED THE AMOUNT 
    OF FEES, IF ANY, THAT YOU HAVE PAID DIRECTLY TO MICROCHIP FOR THIS 
    SOFTWARE.
*/

#include "mcc_generated_files/mcc.h"
#include "dac1_control.h"
/*
                         Main application
 */
void main(void)
{
    // initialize the device
    SYSTEM_Initialize();

    // When using interrupts, you need to set the Global and Peripheral Interrupt Enable bits
    // Use the following macros to:

    // Enable the Global Interrupts
    //INTERRUPT_GlobalInterruptEnable();

    // Enable the Peripheral Interrupts
    //INTERRUPT_PeripheralInterruptEnable();

    // Disable the Global Interrupts
    //INTERRUPT_GlobalInterruptDisable();

    // Disable the Peripheral Interrupts
    //INTERRUPT_PeripheralInterruptDisable();
    
    
    
    
    while (1)
    {
        
    dac1_voltage(0);    // setting voltage, max limit is 4.096v
   
    }
}
/**
 End of File
*/

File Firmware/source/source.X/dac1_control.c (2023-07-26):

/*
 * File:   dac1_control.c
 * Author: user
 *
 * Created on July 24, 2023, 11:27 AM
 */


#include "mcc_generated_files/mcc.h"
#include "dac1_control.h"



    
    
void dac1_voltage_close_loop(float volt){
    uint16_t convertedValue;

    ADC_Initialize();
    ADC_SelectChannel(0x3E);
    ADC_StartConversion();
    convertedValue = ADC_GetConversionResult();
    
}


void dac1_voltage_open_loop(float volt){
    const float volt_max = 4.096;
    
    if (volt > volt_max ){
        volt = volt_max;
    }
    if(volt <= 0){
        volt = 0;
    }
    
    const uint8_t dac_mult = 64;   // 4mv count multiplier
    const float offset  = 0.03;    // 30mv offset ,error +- 1mv
    volt = (volt - offset) ;       // correcting for offset 
    if(volt<0){                    // Correcting of negative voltage
        volt = 0;
    }
    double div = (volt /0.004)  ;  // every one count is 4mv, max 1023
    
    uint16_t count = (dac_mult * div );  // DAC output count, max 65535
    
    DAC1_Load16bitInputData(count); 
    
}

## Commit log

2021-01-16 Basic initial Hardware
    [BoardOutline.gbr, Bottom.gbr, BottomAssy.gbr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]
2021-02-19 deleting design files
    [BoardOutline.gbr, Bottom.gbr, BottomAssy.gbr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]
2021-02-25 adding DipTrace Hardware Files
    [BoardOutline.gbr, Bottom.gbr, BottomAssy.gbr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]
2021-02-25 change file name
    [ELECTRONIC_LOAD_2020.X.production.obj]
2021-03-01 adding floating point support
    [ELECTRONIC_LOAD_2020.X.production.obj, Firmware.production.obj]
2021-03-05 implementing internal OPAMP3 and DAC5
    [Firmware.production.obj]
2021-03-06 changing internal DAC from DAC1 to DAC5 and connecting it to internal OPAMP3 as a first stage buffer
    [Firmware.production.obj]
2021-03-06 adding control board picture
2021-03-11 adding OPAMP3
    [Firmware.production.obj]
2021-04-02 Update Altium files library
    [BoardOutline.gbr, Bottom.gbr, BottomAssy.gbr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]
2021-04-03 starting sechmatic design
    [electronic_dc_load_v1.SchDoc, electronic_dc_load_v1.SchLib]
2021-04-06 Schematic Development
    [electronic_dc_load_v1.SchDoc, electronic_dc_load_v1.SchLib]
2021-04-10 Schematic development
    [digital_components.SchLib, electronic_dc_load_v1.SchDoc, electronic_dc_load_v1.SchLib]
2021-04-22 Schematic update
    [electronic_dc_load_v1.SchDoc, electronic_dc_load_v1.SchLib]
2021-04-24 Schematc analog circuits
    [electronic_dc_load_v1.SchDoc, electronic_dc_load_v1.SchLib]
2021-05-04 Footprint development
    [digital_components.SchLib, electronic_dc_load_v1.PcbLib, electronic_dc_load_v1.PrjPcb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]
2021-05-09 footprint lib development
    [electronic_dc_load_v1.PcbLib, electronic_dc_load_v1.PrjPcb, electronic_dc_load_v1.SchDoc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]
2021-05-23 completed footprint library
    [digital_components.SchLib, electronic_dc_load_v1.PcbDoc, electronic_dc_load_v1.PcbLib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]
2021-05-30 Grid fix
    [digital_components.SchLib, electronic_dc_load_v1.PcbDoc, electronic_dc_load_v1.PcbLib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]
2021-06-04 component placement & PCB preparation
    [electronic_dc_load_v1.PcbDoc, electronic_dc_load_v2.PcbDoc, electronic_dc_load_v2.PrjPcb]
2021-06-05 Layout development
    [Electronic_dc_load_v2.PcbDoc, digital_components.SchLib, electronic_dc_load_v1.PcbLib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]
2021-08-01 PCB Design
    [electronic_dc_load_v1.PcbLib, electronic_dc_load_v1.SchDoc, electronic_dc_load_v1.SchLib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]
2023-05-18 usart library
    [source.X.production.obj]
2023-05-24 ADC functions and header added
    [source.X.production.obj]
2023-05-30 DAC,ADC,FVR,OPA2,OPA3 header filles and library added, and ADC,DAC,FVR,OPA2,OPA3 tested
    [source.X.production.obj]
2023-07-20 ADC Vref calibration
    [source.X.production.obj]
2023-07-22 clock config 32M
    [source.X.production.obj]
2023-07-24 dac1 config
    [source.X.production.obj]
2023-07-24 dac1 voltage set fuction
    [source.X.production.obj]
2023-07-26 added FVR config
    [electronic_dc_load_v1.SchDoc, source.X.production.obj]
